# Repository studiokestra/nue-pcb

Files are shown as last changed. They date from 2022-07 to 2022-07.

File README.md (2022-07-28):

# Nue PCB rev1.1

Nue PCB

This is the open source PCB for the Nue keyboard. It's minimally designed (as intentioned) with ISO support and basic 60% layout options. The Nue PCB has gasket mounting tabs and as such will not work on any other keyboard. Fuse / ESD protection was not implemented initially as this was taken care of by the unifed C3 daughterboard, however future revisions will have it onboard as backup. These files are provided as-is and are intended for tinkerers, do not expect warranty or support to be provided.

## Features
- Designed with KiCad 6.0+
- Compatible with QMK/VIA
- Only works with Nue PCB
- Utilizes Unified C3 daughterboard or compatible equivalents
- ISP header

## Supported layouts
Supported Nue layouts

## Ordering
The files necessary to produce the PCBs via JLCPCB are located in the production folder.

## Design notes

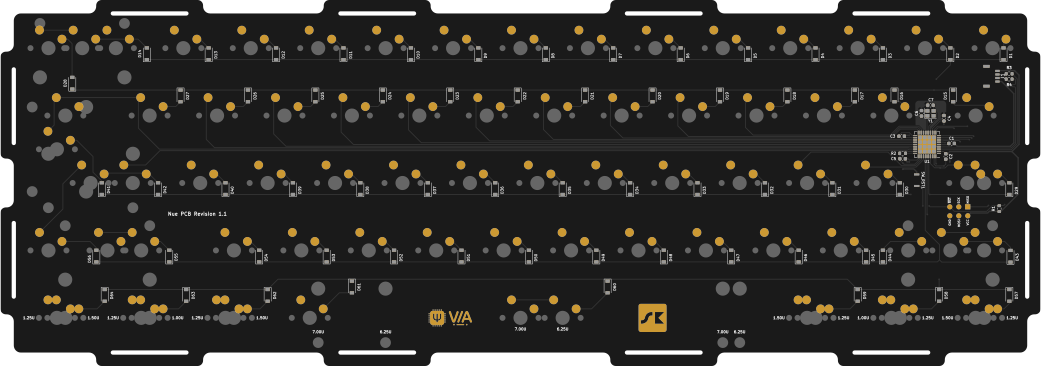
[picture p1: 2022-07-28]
design files/top.png

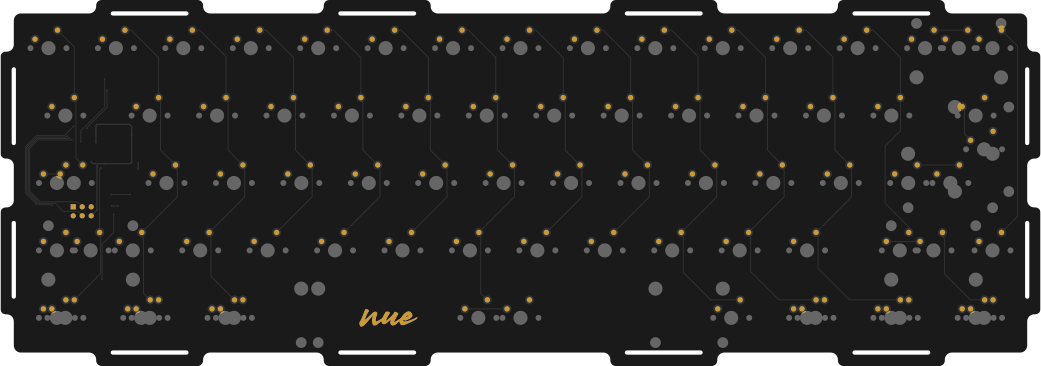
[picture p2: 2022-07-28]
design files/bottom.png

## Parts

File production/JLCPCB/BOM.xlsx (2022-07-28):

Comment | Designator | Footprint | LCSC Part #（optional）
ATmega32U4-MU | U1 | QFN-44-1EP_7x7mm_P0.5mm_EP5.2x5.2mm | C45874
16 MHz | Y1 | Crystal_SMD_2520-4Pin_2.5x2.0mm | C284159
SW_Push | SW_RST1 | smdPushBtn | C319436
22 | R4,R3 | R_0603_1608Metric | C23345
1k | R2 | R_0603_1608Metric | C21190
10k | R1 | R_0603_1608Metric | C25804
22pF | C7,C6 | C_0603_1608Metric | C1653
0.1uF | C5,C4,C3 | C_0603_1608Metric | C14663
10uF | C2 | C_0603_1608Metric | C19702
1uF | C1 | C_0603_1608Metric | C15849
1N4148 | D1,D2,D3,D4,D5,D6,D7,D8,D9,D10,D11,D12,D13,D14,D15,D16,D17,D18,D19,D20,D21,D22,D23,D24,D25,D26,D27,D29,D30,D31,D32,D33,D34,D35,D36,D37,D38,D39,D42,D43,D44,D45,D46,D47,D48,D49,D50,D51,D52,D53,D54,D55,D56,D57,D58,D59,D60,D61,D63,D64,D28,D62,D41,D40 | D_SOD-123 | C81598
Conn_01x04 | J1 | JST_BM04B-ASRS | C160404

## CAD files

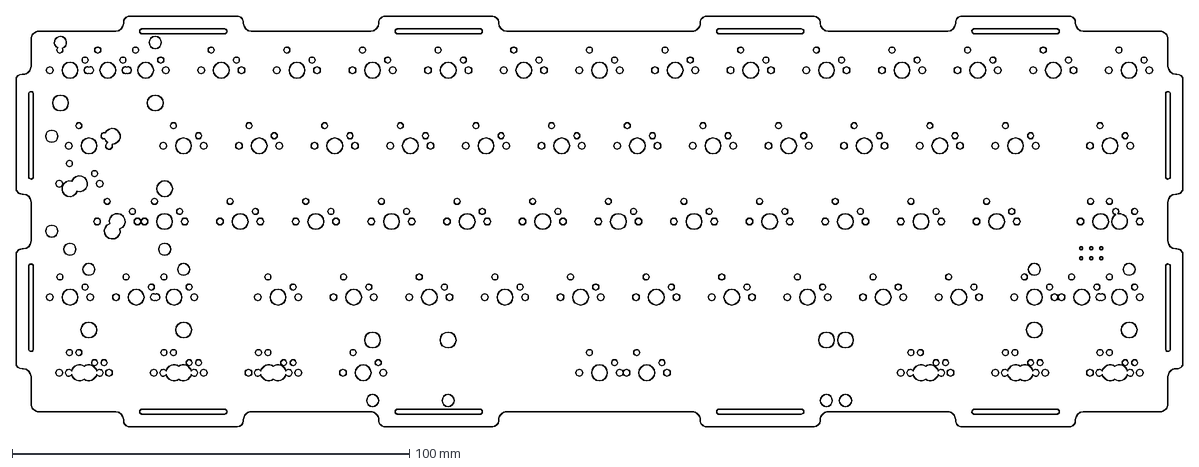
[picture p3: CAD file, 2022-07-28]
design files/pcb-outline.dxf
293.9 x 103.4 mm

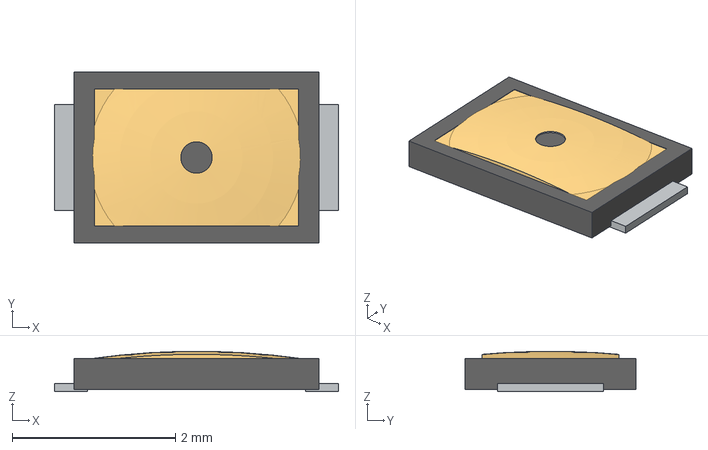
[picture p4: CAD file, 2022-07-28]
kicad/kestralib/3x2x0.65mm.stp
3.48 x 2.10 x 0.493 mm

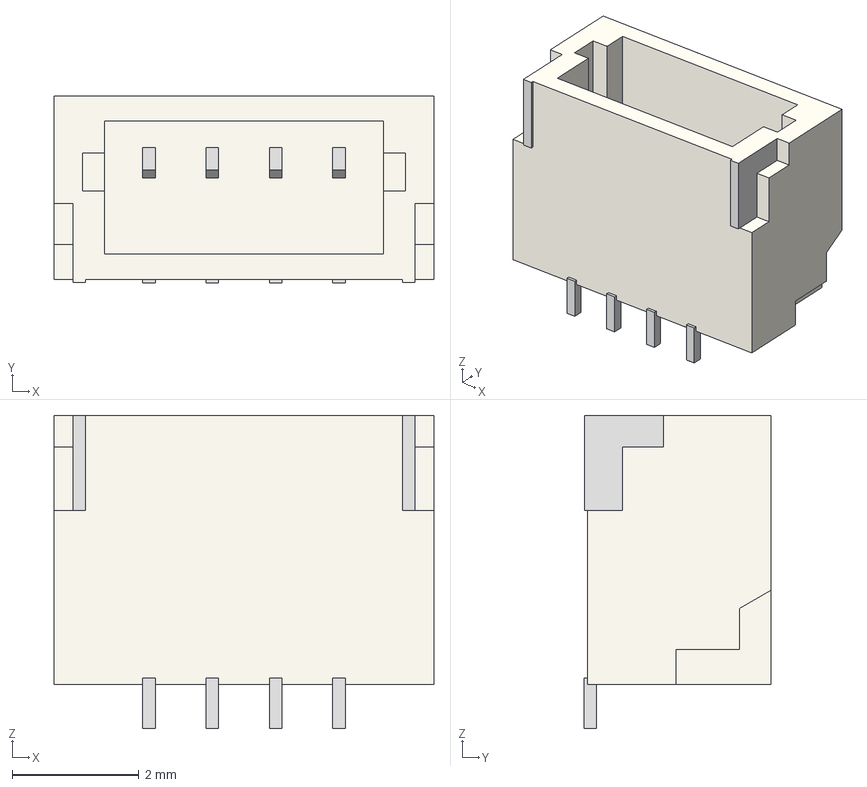
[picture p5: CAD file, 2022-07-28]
kicad/kestralib/SM04B-SRSS-TB.STEP
6.00 x 2.96 x 4.95 mm

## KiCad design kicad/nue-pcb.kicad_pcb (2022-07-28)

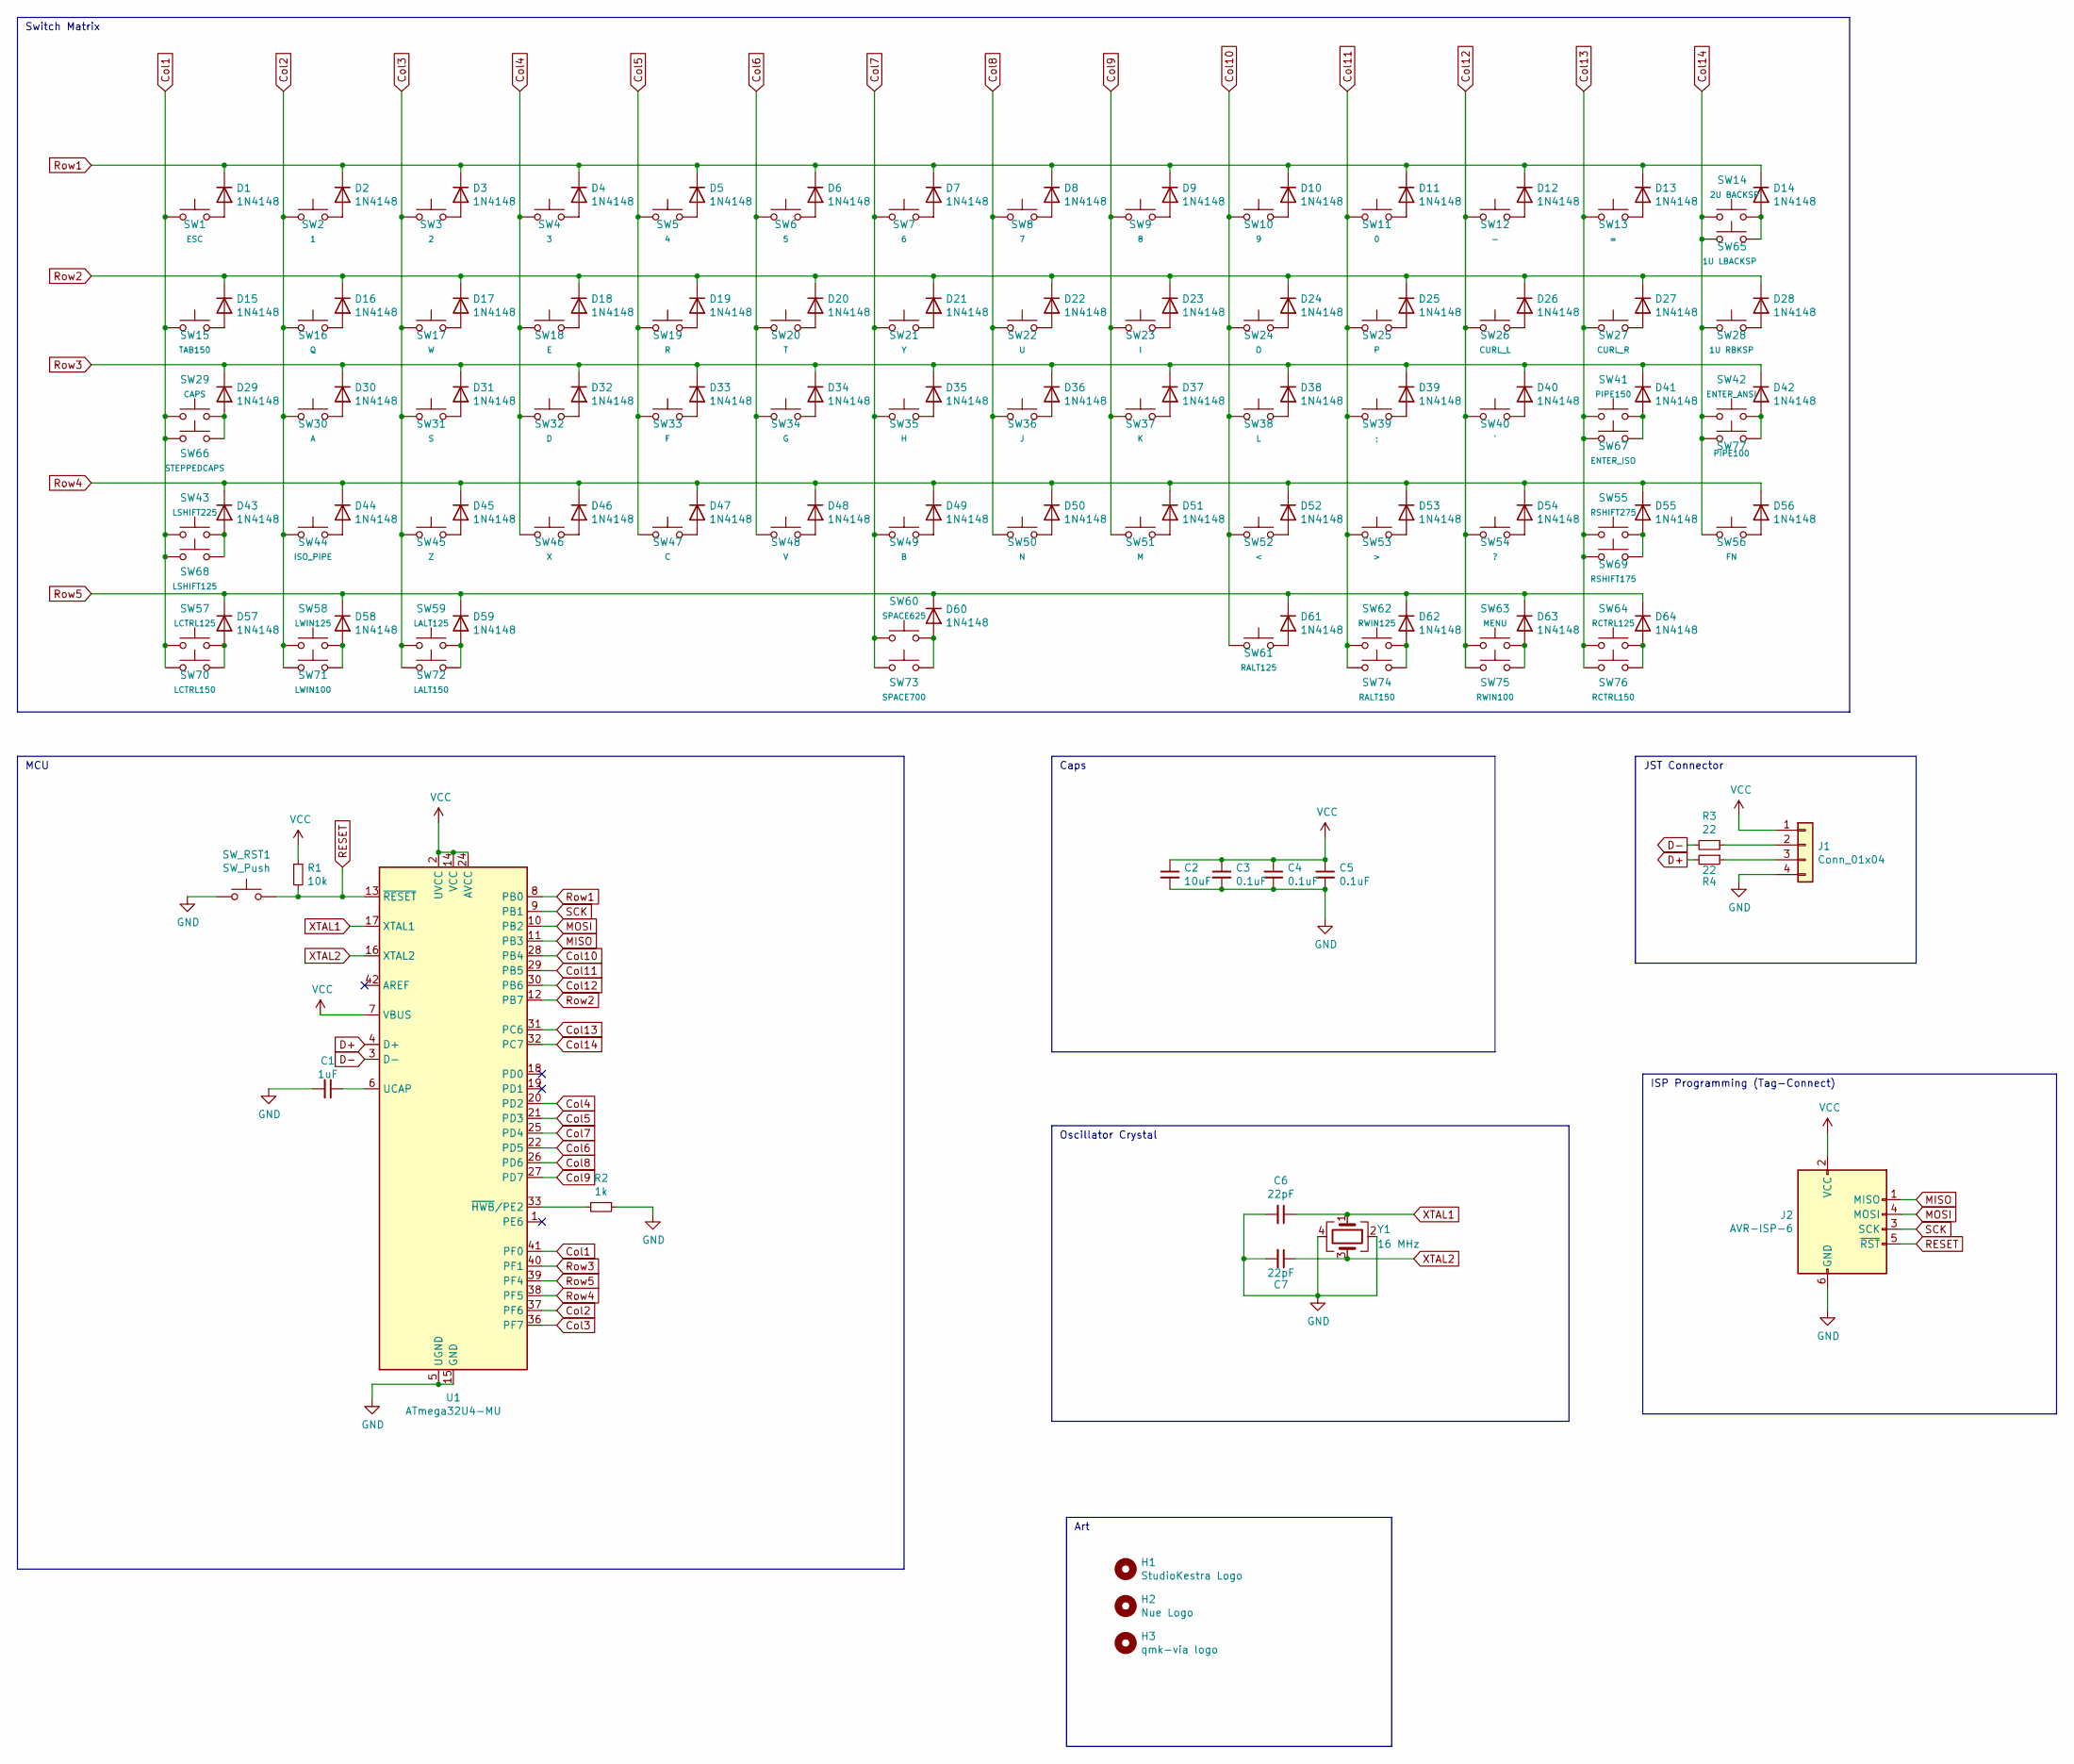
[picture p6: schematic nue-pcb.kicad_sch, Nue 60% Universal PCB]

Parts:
C1: 1uF; C_0603_1608Metric
C2: 10uF; C_0603_1608Metric
C3, C4, C5: 0.1uF; C_0603_1608Metric
C6, C7: 22pF; C_0603_1608Metric
D1, D2, D3, D4, D5, D6, D7, D8, D9, D10, D11, D12, D13, D14, D15, D16, D17, D18, D19, D20, D21, D22, D23, D24, D25, D26, D27, D28, D29, D30, D31, D32, D33, D34, D35, D36, D37, D38, D39, D40, D41, D42, D43, D44, D45, D46, D47, D48, D49, D50, D51, D52, D53, D54, D55, D56, D57, D58, D59, D60, D61, D62, D63, D64: 1N4148; D_SOD-123
H1: StudioKestra Logo; sk-square-mask-md
H2: Nue Logo; nue-logo
H3: qmk-via logo; qmk-via
J1: Conn_01x04; JST_BM04B-ASRS
J2: AVR-ISP-6; Conn_AVR_ISP_6
R1: 10k; R_0603_1608Metric
R2: 1k; R_0603_1608Metric
R3, R4: 22; R_0603_1608Metric
SW1: ESC; MX100
SW2: 1; MX100
SW3: 2; MX100
SW4: 3; MX100
SW5: 4; MX100
SW6: 5; MX100
SW7: 6; MX100
SW8: 7; MX100
SW9: 8; MX100
SW10: 9; MX100
SW11: 0; MX100
SW12: -; MX100
SW13: =; MX100
SW14: 2U BACKSP; MX200
SW15: TAB150; MX150
SW16: Q; MX100
SW17: W; MX100
SW18: E; MX100
SW19: R; MX100
SW20: T; MX100
SW21: Y; MX100
SW22: U; MX100
SW23: I; MX100
SW24: O; MX100
SW25: P; MX100
SW26: CURL_L; MX100
SW27: CURL_R; MX100
SW28: 1U RBKSP; MX100
SW29: CAPS; MX175
SW30: A; MX100
SW31: S; MX100
SW32: D; MX100
SW33: F; MX100
SW34: G; MX100
SW35: H; MX100
SW36: J; MX100
SW37: K; MX100
SW38: L; MX100
SW39: ;; MX100
SW40: '; MX100
SW41: PIPE150; MX150
SW42: ENTER_ANSI; MX225R
SW43: LSHIFT225; MX225
SW44: ISO_PIPE; MX100
SW45: Z; MX100
SW46: X; MX100
SW47: C; MX100
SW48: V; MX100
SW49: B; MX100
SW50: N; MX100
SW51: M; MX100
SW52: <; MX100
SW53: >; MX100
SW54: ?; MX100
SW55: RSHIFT275; MX275
SW56: FN; MX100
SW57: LCTRL125; MX125
SW58: LWIN125; MX125
SW59: LALT125; MX125
SW60: SPACE625; MX625R
SW61: RALT125; MX125
SW62: RWIN125; MX125
SW63: MENU; MX125
SW64: RCTRL125; MX125
SW65: 1U LBACKSP; MX100
SW66: STEPPEDCAPS; MX125
SW67: ENTER_ISO; MXISOEnter
SW68: LSHIFT125; MX125
SW69: RSHIFT175; MX175
SW70: LCTRL150; MX150
SW71: LWIN100; MX100
SW72: LALT150; MX150
SW73: SPACE700; MX700R
SW74: RALT150; MX150
SW75: RWIN100; MX100
SW76: RCTRL150; MX150
SW77: PIPE100; MX100
SW_RST1: SW_Push; pushbtn_C319436
U1: ATmega32U4-MU; QFN-44-1EP_7x7mm_P0.5mm_EP5.2x5.2mm
Y1: 16 MHz; Crystal_SMD_2520-4Pin_2.5x2.0mm

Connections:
Col1: SW1.1, SW15.1, SW29.1, SW43.1, SW57.1, SW66.1, SW68.1, SW70.1, U1.41 (PF0)
Col2: SW2.1, SW16.1, SW30.1, SW44.1, SW58.1, SW71.1, U1.37 (PF6)
Col3: SW3.1, SW17.1, SW31.1, SW45.1, SW59.1, SW72.1, U1.36 (PF7)
Col4: SW4.1, SW18.1, SW32.1, SW46.1, U1.20 (PD2)
Col5: SW5.1, SW19.1, SW33.1, SW47.1, U1.21 (PD3)
Col6: SW6.1, SW20.1, SW34.1, SW48.1, U1.22 (PD5)
Col7: SW7.1, SW21.1, SW35.1, SW49.1, SW60.1, SW73.1, U1.25 (PD4)
Col8: SW8.1, SW22.1, SW36.1, SW50.1, U1.26 (PD6)
Col9: SW9.1, SW23.1, SW37.1, SW51.1, U1.27 (PD7)
Col10: SW10.1, SW24.1, SW38.1, SW52.1, SW61.1, U1.28 (PB4)
Col11: SW11.1, SW25.1, SW39.1, SW53.1, SW62.1, SW74.1, U1.29 (PB5)
Col12: SW12.1, SW26.1, SW40.1, SW54.1, SW63.1, SW75.1, U1.30 (PB6)
Col13: SW13.1, SW27.1, SW41.1, SW55.1, SW64.1, SW67.1, SW69.1, SW76.1, U1.31 (PC6)
Col14: SW14.1, SW28.1, SW42.1, SW56.1, SW65.1, SW77.1, U1.32 (PC7)
D+: R4.2, U1.4 (D+)
D-: R3.2, U1.3 (D-)
GND: C1.2, C2.2, C3.2, C4.2, C5.2, C6.2, C7.2, J1.4, J2.6 (GND), R2.1, SW_RST1.1, U1.5 (UGND), U1.15 (GND), U1.23 (GND), U1.35 (GND), U1.43 (GND), U1.45 (GND), Y1.2, Y1.4
MISO: J2.1 (MISO), U1.11 (PB3)
MOSI: J2.4 (MOSI), U1.10 (PB2)
unnamed: C1.1, U1.6 (UCAP)
unnamed: D1.2 (A), SW1.2
unnamed: D2.2 (A), SW2.2
unnamed: D3.2 (A), SW3.2
unnamed: D4.2 (A), SW4.2
unnamed: D5.2 (A), SW5.2
unnamed: D6.2 (A), SW6.2
unnamed: D7.2 (A), SW7.2
unnamed: D8.2 (A), SW8.2
unnamed: D9.2 (A), SW9.2
unnamed: D10.2 (A), SW10.2
unnamed: D11.2 (A), SW11.2
unnamed: D12.2 (A), SW12.2
unnamed: D13.2 (A), SW13.2
unnamed: D14.2 (A), SW14.2, SW65.2
unnamed: D15.2 (A), SW15.2
unnamed: D16.2 (A), SW16.2
unnamed: D17.2 (A), SW17.2
unnamed: D18.2 (A), SW18.2
unnamed: D19.2 (A), SW19.2
unnamed: D20.2 (A), SW20.2
unnamed: D21.2 (A), SW21.2
unnamed: D22.2 (A), SW22.2
unnamed: D23.2 (A), SW23.2
unnamed: D24.2 (A), SW24.2
unnamed: D25.2 (A), SW25.2
unnamed: D26.2 (A), SW26.2
unnamed: D27.2 (A), SW27.2
unnamed: D28.2 (A), SW28.2
unnamed: D29.2 (A), SW29.2, SW66.2
unnamed: D30.2 (A), SW30.2
unnamed: D31.2 (A), SW31.2
unnamed: D32.2 (A), SW32.2
unnamed: D33.2 (A), SW33.2
unnamed: D34.2 (A), SW34.2
unnamed: D35.2 (A), SW35.2
unnamed: D36.2 (A), SW36.2
unnamed: D37.2 (A), SW37.2
unnamed: D38.2 (A), SW38.2
unnamed: D39.2 (A), SW39.2
unnamed: D40.2 (A), SW40.2
unnamed: D41.2 (A), SW41.2, SW67.2
unnamed: D42.2 (A), SW42.2, SW77.2
unnamed: D43.2 (A), SW43.2, SW68.2
unnamed: D44.2 (A), SW44.2
unnamed: D45.2 (A), SW45.2
unnamed: D46.2 (A), SW46.2
unnamed: D47.2 (A), SW47.2
unnamed: D48.2 (A), SW48.2
unnamed: D49.2 (A), SW49.2
unnamed: D50.2 (A), SW50.2
unnamed: D51.2 (A), SW51.2
unnamed: D52.2 (A), SW52.2
unnamed: D53.2 (A), SW53.2
unnamed: D54.2 (A), SW54.2
unnamed: D55.2 (A), SW55.2, SW69.2
unnamed: D56.2 (A), SW56.2
unnamed: D57.2 (A), SW57.2, SW70.2
unnamed: D58.2 (A), SW58.2, SW71.2
unnamed: D59.2 (A), SW59.2, SW72.2
unnamed: D60.2 (A), SW60.2, SW73.2
unnamed: D61.2 (A), SW61.2
unnamed: D62.2 (A), SW62.2, SW74.2
unnamed: D63.2 (A), SW63.2, SW75.2
unnamed: D64.2 (A), SW64.2, SW76.2
unnamed: J1.2, R3.1
unnamed: J1.3, R4.1
unnamed: R2.2, U1.33 (~HWB/PE2)
RESET: J2.5 (~RST), R1.2, SW_RST1.2, U1.13 (~RESET)
Row1: D1.1 (K), D2.1 (K), D3.1 (K), D4.1 (K), D5.1 (K), D6.1 (K), D7.1 (K), D8.1 (K), D9.1 (K), D10.1 (K), D11.1 (K), D12.1 (K), D13.1 (K), D14.1 (K), U1.8 (PB0)
Row2: D15.1 (K), D16.1 (K), D17.1 (K), D18.1 (K), D19.1 (K), D20.1 (K), D21.1 (K), D22.1 (K), D23.1 (K), D24.1 (K), D25.1 (K), D26.1 (K), D27.1 (K), D28.1 (K), U1.12 (PB7)
Row3: D29.1 (K), D30.1 (K), D31.1 (K), D32.1 (K), D33.1 (K), D34.1 (K), D35.1 (K), D36.1 (K), D37.1 (K), D38.1 (K), D39.1 (K), D40.1 (K), D41.1 (K), D42.1 (K), U1.40 (PF1)
Row4: D43.1 (K), D44.1 (K), D45.1 (K), D46.1 (K), D47.1 (K), D48.1 (K), D49.1 (K), D50.1 (K), D51.1 (K), D52.1 (K), D53.1 (K), D54.1 (K), D55.1 (K), D56.1 (K), U1.38 (PF5)
Row5: D57.1 (K), D58.1 (K), D59.1 (K), D60.1 (K), D61.1 (K), D62.1 (K), D63.1 (K), D64.1 (K), U1.39 (PF4)
SCK: J2.3 (SCK), U1.9 (PB1)
VCC: C2.1, C3.1, C4.1, C5.1, J1.1, J2.2 (VCC), R1.1, U1.2 (UVCC), U1.7 (VBUS), U1.14 (VCC), U1.24 (AVCC), U1.34 (VCC), U1.44 (AVCC)
XTAL1: C6.1, U1.17 (XTAL1), Y1.1
XTAL2: C7.1, U1.16 (XTAL2), Y1.3

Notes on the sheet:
Oscillator Crystal
MCU
ISP Programming (Tag-Connect)
JST Connector
Caps
Switch Matrix
Art

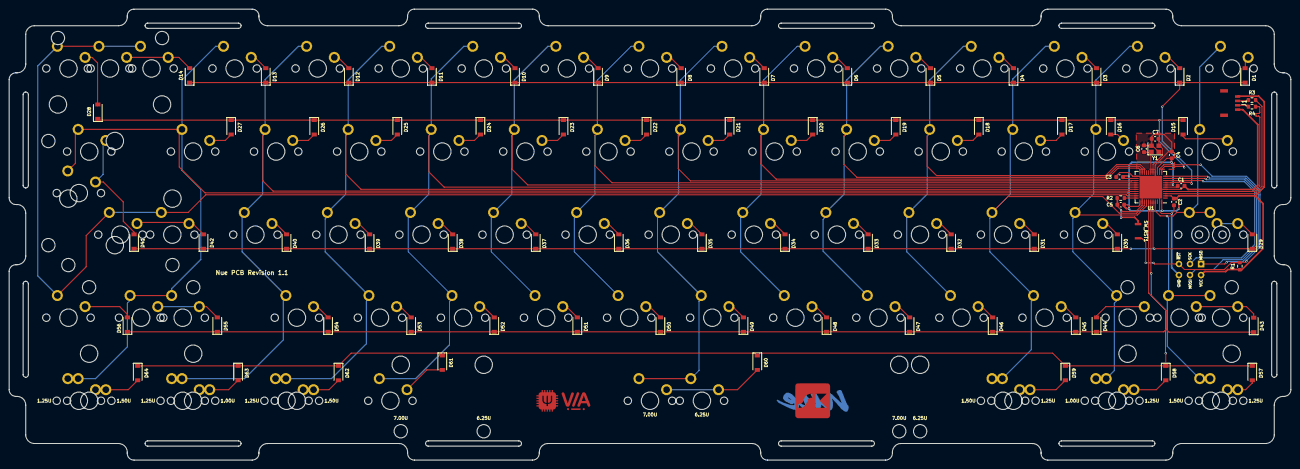
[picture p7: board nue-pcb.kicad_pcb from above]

Board: 2 copper layers, 293.9 x 103.4 mm, 160 parts (1 on the bottom side), 97 nets.
